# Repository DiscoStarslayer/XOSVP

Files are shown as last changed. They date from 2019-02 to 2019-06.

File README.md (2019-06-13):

# Xbox Open Source Video Project
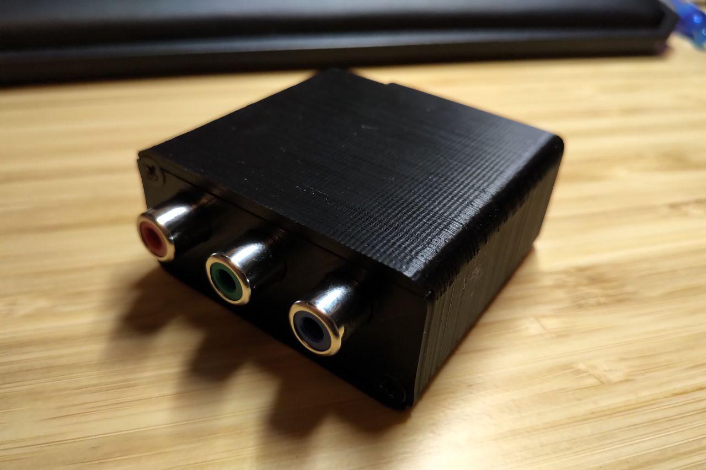
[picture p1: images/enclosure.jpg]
Finished XOSVP Image

XOSVP is an open-source alternative to the Microsoft HD AV Pack. The XOSVP strives to produce the absolute best analog video quality out of your original Xbox.

## Features
- Highest possible quality analog Y/Pb/Pr component video out
    - Impedance matched board traces and cabling from original Xbox
    - High quality video filter + amplifier, [THS7316](https://www.ti.com/lit/ds/symlink/ths7316.pdf)
        - Low pass filter removes high-frequency noise and aberrations from the source signal without harming video frequencies
        - Reconstructs + Amplifies original signal to ensure matching with the Y/Pb/Pr Standards
        - Reduces DAC Imaging effects on the video receiver
- Optical Audio/SPDIF
    - Best possible audio quality from the original Xbox
    - Support Stereo -> 5.1 Surround Sound
    - Cheap, high-quality optical DAC's easy to source on Amazon/Ebay for those without stereo systems

## More Details
[Check out my in-depth blog post on the XOSVP detailing its construction, evolution, and comparison images.](https://blog.dtho.mp/2018/12/15/xosvp-intro/)

## Designs
- [**Schematics**](/xosvp.pdf)
- [**PCB**](/pcb.png)
- [**BOM**](/bom.csv)
- [**Enclosure**](/enclosure.obj)

All designs are produced with KiCAD 5. This includes all schematic sources, designed footprints, and PCB layout.

## Enclosure
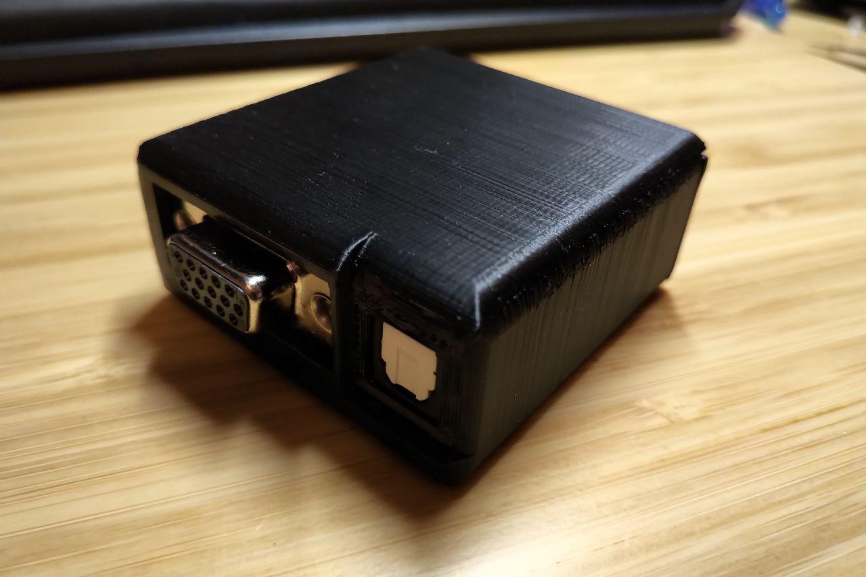
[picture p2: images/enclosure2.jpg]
XOSVP Enclosure

Also within this repo is a 3D printable enclosure for the XOSVP. It is designed for friction fit so please ensure your 3D printer is calibrated properly before printing. All files were exported with Millimeter scale.

The enclosure was designed with Tinkercad, and you can view this design [HERE](https://www.tinkercad.com/things/6Rlx4JstT6S-xosvp-enclosure-v3).

## License
I want high-quality analog video from the original Xbox to be available to everyone, which is why I open sourced this project. Everything within this repo is covered by [CERN Open Hardware License v1.2](/LICENSE).

## Contributing
If you have any suggested changes/improvements, please feel free to create an issue or a PR. They will be happily accepted!

# Build Instructions

## Kit
The Following image contains all the parts in the BOM/XOSVP DIY Kit:
Kit Contents

## PCB Installation

The parts are placed on the board in the following configuration
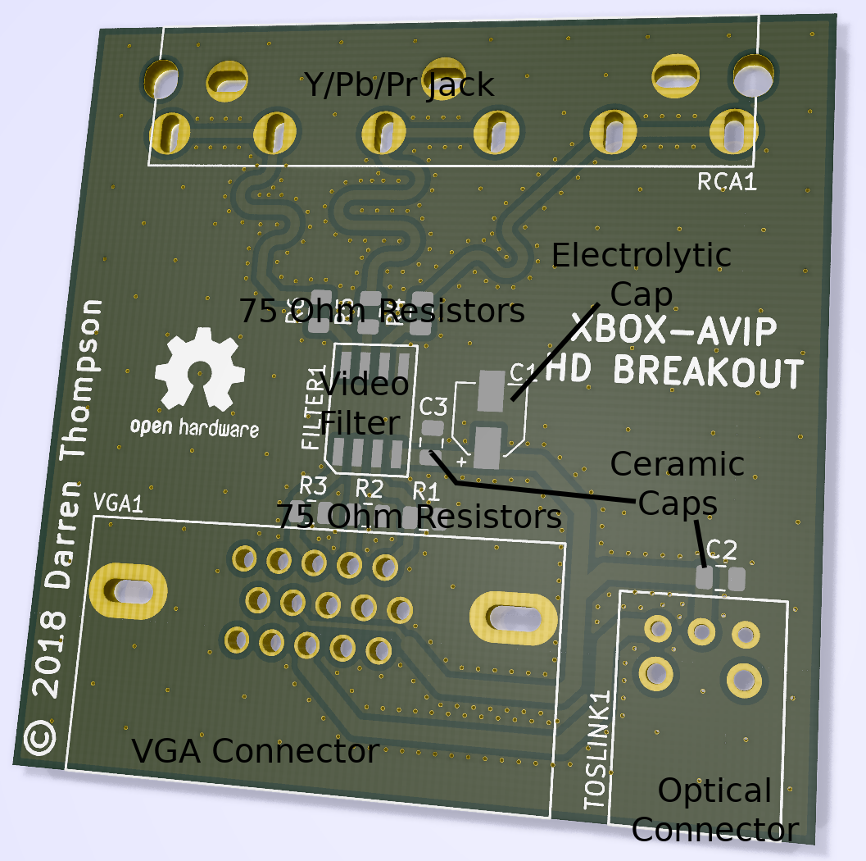
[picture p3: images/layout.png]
PCB Layout


The 3D Printed enclosure is designed for a friction fit, so it is very important that the Y/Pb/Pr jack and VGA connector are completely flush to the PCB like in the following image:
Flush Y/Pb/Pr connector

## AVIP to XOSVP
XOSVP Adapter
To make the cable that connects the Xbox to the AVIP, you will need to splice the included AVIP connector with the included VGA cable.

Creating this cable is a rather involved process, and you want to get it right, so I created the following video tutorial to document the process I follow when making them.

[**YouTube Video Tutorial**](https://www.youtube.com/watch?v=ltjp-2m_H6U)

The following pinouts are provided for extra detail and are intended to be used alongside the video tutorial.

This splice must follow the following pinout guide

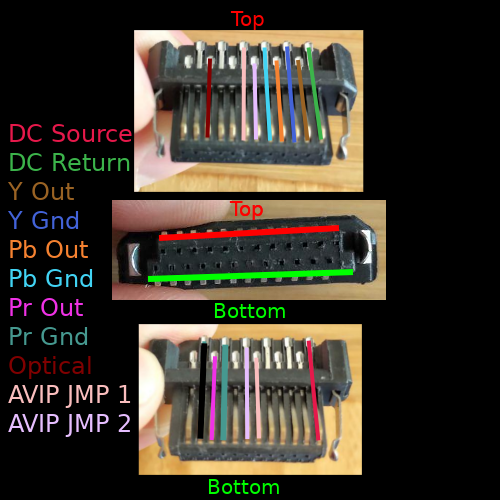
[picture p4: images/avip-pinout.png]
AVIP Pinout


Each of the colored AVIP pins must be connected so that they match the following pinout of the VGA cable. The only exception is the `AVIP JMP 1` and `AVIP JMP 2` pins. These need to be jumped together on the top + bottom of the AVIP connector.

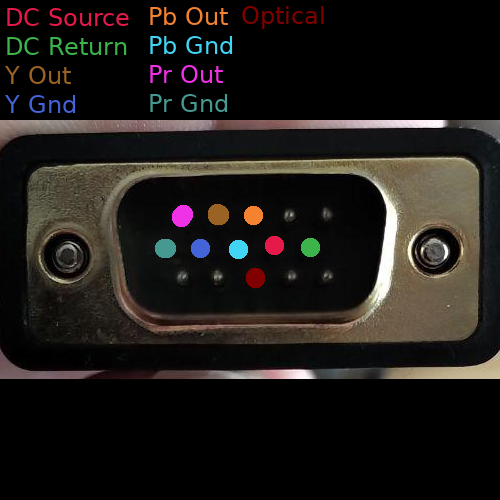
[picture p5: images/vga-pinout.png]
VGA Pinout


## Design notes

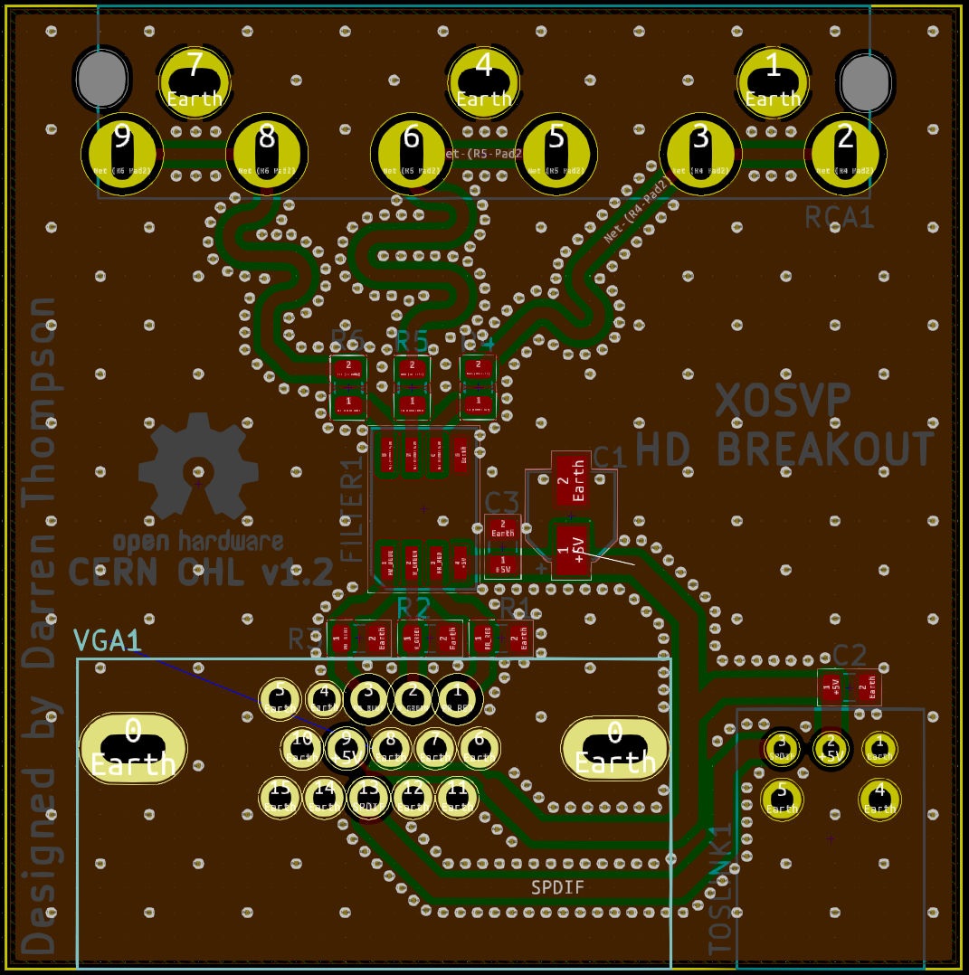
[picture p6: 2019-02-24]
pcb.png

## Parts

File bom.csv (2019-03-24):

Designator | MPN | Qty | Link
R1,R2,R3,R4,R5,R6 | CR0805-FX-75R0ELF | 6 | https://www.digikey.ca/product-detail/en/bourns-inc/CR0805-FX-75R0ELF/CR0805-FX-75R0ELFCT-ND/3740930
C1 | UCL1C100MCL1GS | 1 | https://www.digikey.ca/product-detail/en/nichicon/UCL1C100MCL1GS/493-3913-1-ND/2300340
C2,C3 | CL21B104KCFNNNE | 2 | https://www.digikey.ca/product-detail/en/samsung-electro-mechanics/CL21B104KCFNNNE/1276-6840-1-ND/5961699
FILTER1 | THS7316DR | 1 | https://www.digikey.ca/product-detail/en/texas-instruments/THS7316DR/296-26684-1-ND/2255104
VGA1 | AHDF15A-KG-TAXB | 1 | https://www.digikey.ca/product-detail/en/assmann-wsw-components/AHDF15A-KG-TAXB/AE11024-ND/1241905
RCA1 | PJRAN3X1U03X | 1 | https://www.digikey.ca/product-detail/en/switchcraft-inc/PJRAN3X1U03X/SC1854-ND/1288816
TOSLINK1 | PLT133/T10W | 1 | https://www.digikey.ca/product-detail/en/everlight-electronics-co-ltd/PLT133-T10W/1080-1430-ND/2693977
Enclosure Screw | 1455MS100BK | 2 | https://www.digikey.ca/product-detail/en/hammond-manufacturing/1455MS100BK/HM1426-ND/3869037
VGA Cable | Monoprice #5361 | 1 | https://www.monoprice.com/product?p_id=85
AVIP Connector | unk | 1 | null

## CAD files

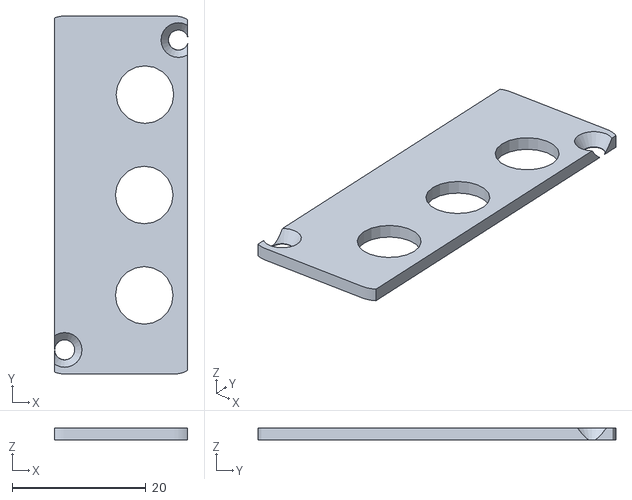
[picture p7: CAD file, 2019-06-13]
enclosure.stl
19.9 x 53.5 x 1.80

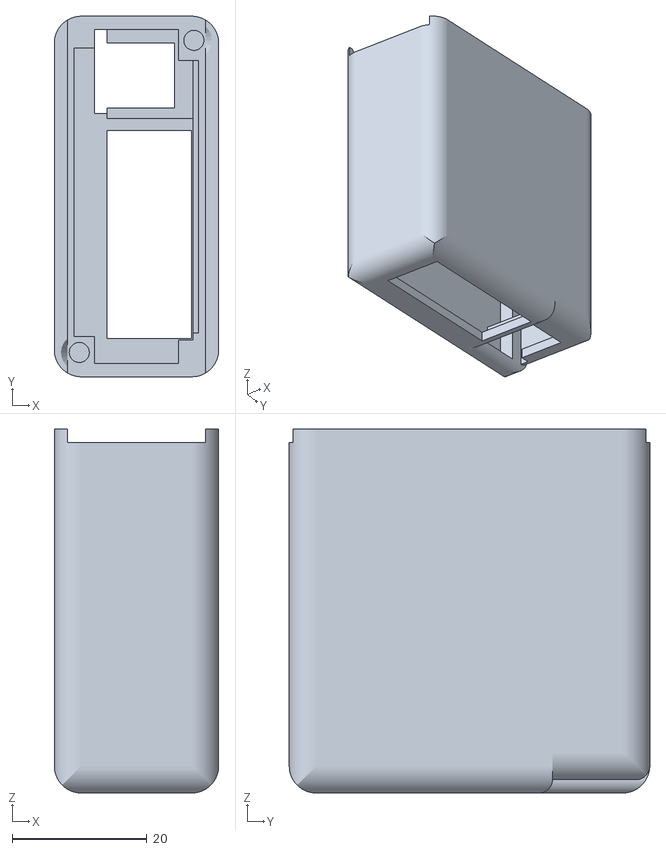
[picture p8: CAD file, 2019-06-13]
enclosure_faceplate.stl
24.4 x 53.5 x 54.0

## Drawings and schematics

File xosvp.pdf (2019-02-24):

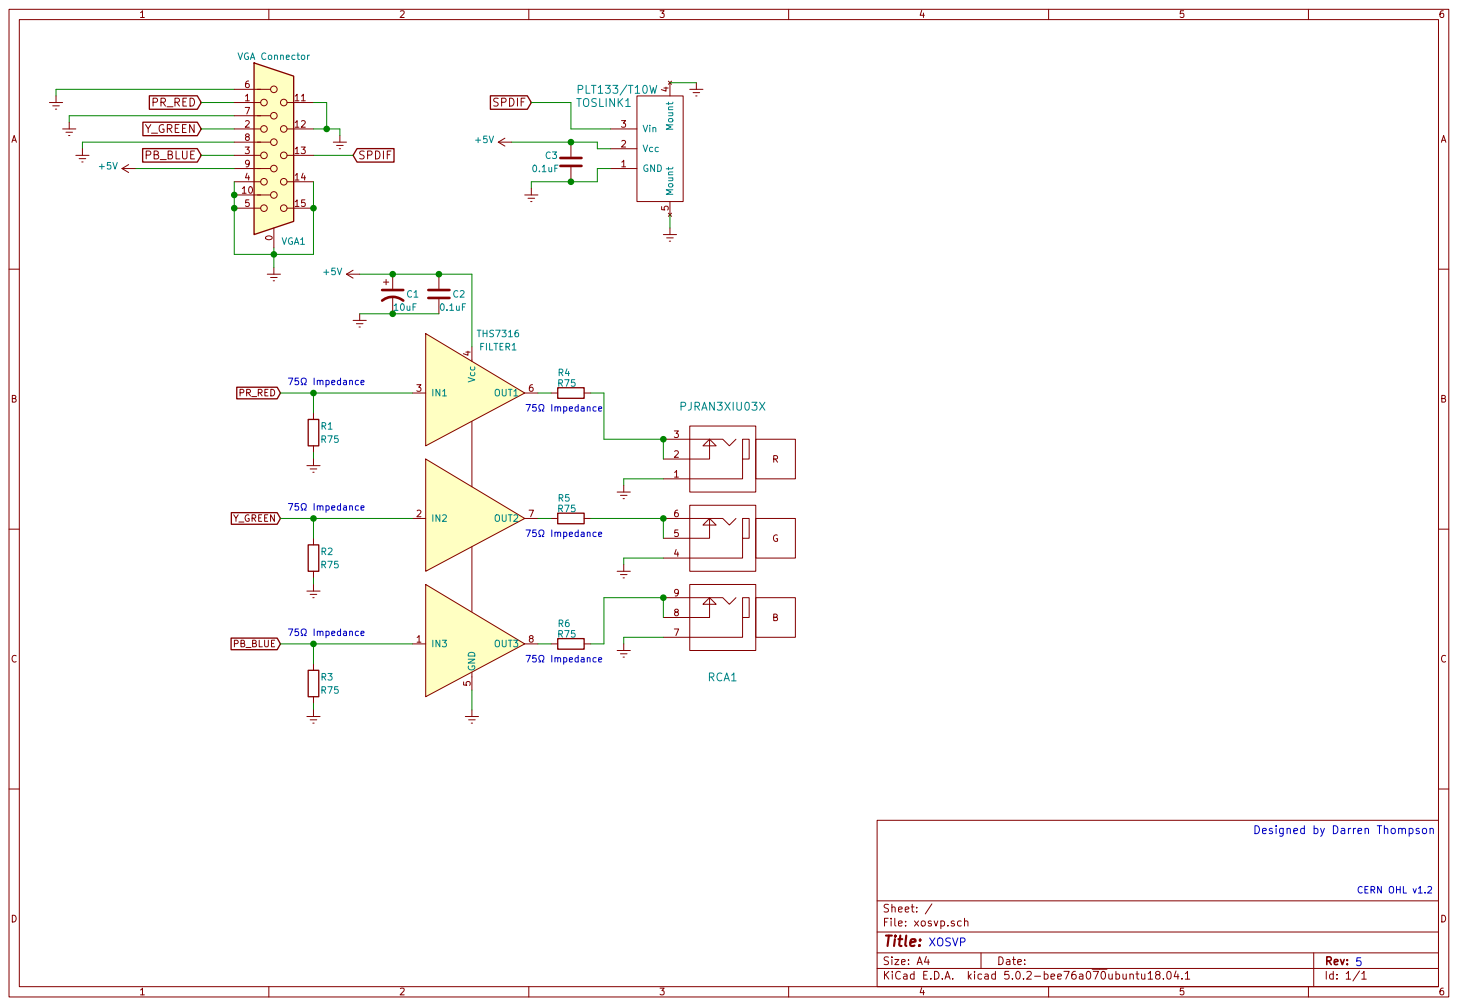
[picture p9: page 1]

5 Designed by Darren Thompson

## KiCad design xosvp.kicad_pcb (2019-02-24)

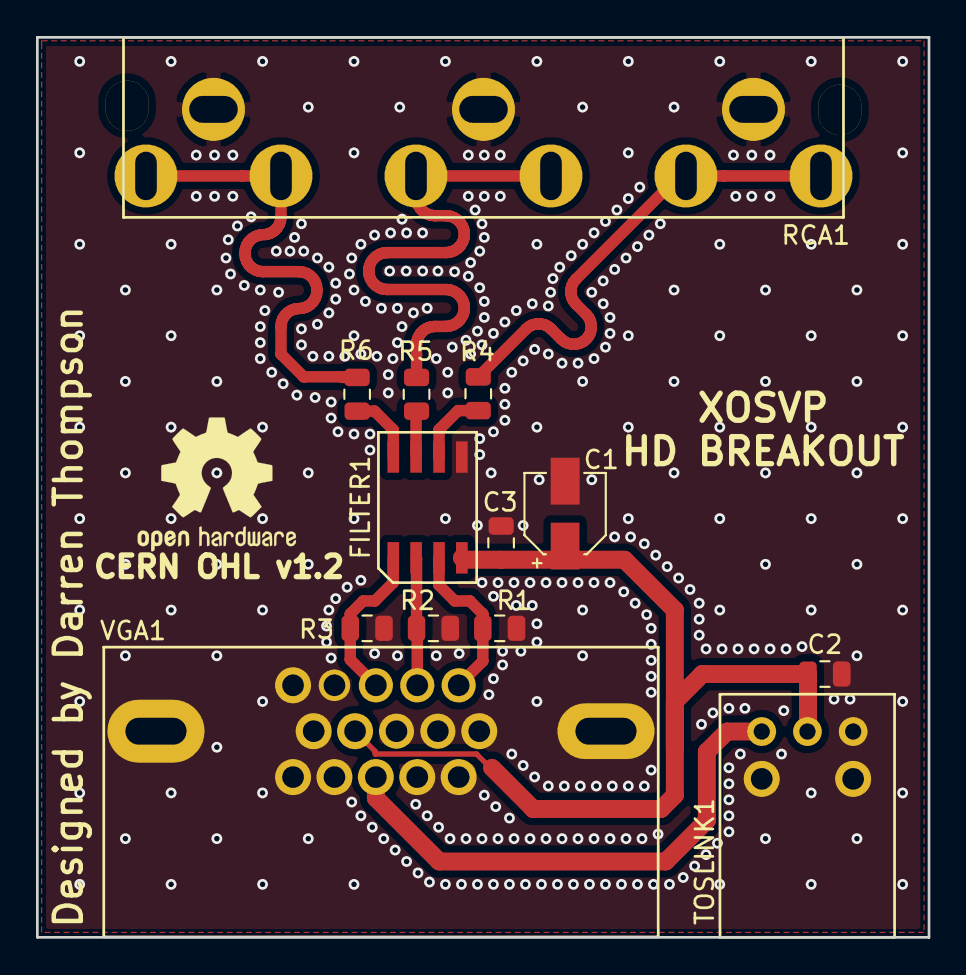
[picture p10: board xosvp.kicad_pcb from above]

Board: 2 copper layers, 49.5 x 50.0 mm, 13 parts (0 on the bottom side), 12 nets.

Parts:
C1: 10uF; CP_Elec_4x5.8
C2, C3: 0.1uF; C_0805_2012Metric
FILTER1: THS7316
R1, R2, R3, R4, R5, R6: R75; R_0805_2012Metric
RCA1: PJRAN3XIU03X; PJRAN3X1U
TOSLINK1: PLT133/T10W; PLT133
VGA1: VGA Connector; AHDF15A

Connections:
+5V: C1.1, C2.1, C3.1, FILTER1.4, TOSLINK1.2, VGA1.9
Earth: C1.2, C2.2, C3.2, FILTER1.5, R1.2, R2.2, R3.2, RCA1.1, RCA1.4, RCA1.7, TOSLINK1.1, TOSLINK1.4, TOSLINK1.5, VGA1.0, VGA1.4, VGA1.5, VGA1.6, VGA1.7, VGA1.8, VGA1.10, VGA1.11, VGA1.12, VGA1.14, VGA1.15
unnamed: FILTER1.6, R4.1
unnamed: FILTER1.7, R5.1
unnamed: FILTER1.8, R6.1
unnamed: R4.2, RCA1.2, RCA1.3
unnamed: R5.2, RCA1.5, RCA1.6
unnamed: R6.2, RCA1.8, RCA1.9
PB_BLUE: FILTER1.1, R3.1, VGA1.3
PR_RED: FILTER1.3, R1.1, VGA1.1
SPDIF: TOSLINK1.3, VGA1.13
Y_GREEN: FILTER1.2, R2.1, VGA1.2

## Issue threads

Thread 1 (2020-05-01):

Screen turned brighter all of a sudden

BanjoBanana, 2020-05-01:
I am using my XOSVP quiet a while now and i am enjoying it very much so far. After a few weeks of usage my screen turned brighter all of a sudden without any reason.

At the beginning i was able to get rid of the problem by bending the video cable a bit or by touching, which doesn‘t make any sense for me. But that worked only for a few seconds. The screen did not get any darker ever since.

I double checked every connection from AV-connector to the board. Everything seems fine. There are no solder bridges or anything. I am using an OSSC and a mClassic to get a crisper image. I haven‘t got any issues whatsoever.

What could cause this problem so that at least i know where to search? Have you ever encountered an issue like this? I would appreciate your help very much and keep up the good work!

Best regards

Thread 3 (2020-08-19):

combine analog and digital audio in one connector to enable both audio options "natively"

moosdev, 2020-08-19:
By using a regular 3.5mm TRS phone socket and a LED instead of the exclusively optical TOSLINK connector it's possible to provide optical and analog audio (with a Mini-Toslink or 3.5mm TRS cable, respectively) in one connector (and consequently gets rid of the DAC requirement if analog audio is needed).

I've come across that convenient fact when I first dug through the [MiSTer (github-)project](https://github.com/MiSTer-devel/Main_MiSTer/wiki) and its wiki.
The [IO addon board](https://github.com/MiSTer-devel/Main_MiSTer/wiki/IO-Board-Assembly-(DIY)) for it has an 3.5mm TRS phone connector (BOM: J2, BOM+schematics for further review is accessible on the linked github) which does exactly that by using a LED (BOM: LED4) behind the connector on the PCB.
[And apparently this is something which is/was used in other commercial products.](https://en.wikipedia.org/wiki/TOSLINK#Mini-TOSLINK)
(I have an assembled IO-Board on hand and can take a close-up shot of the connector and LED behind it, if needed for clarification.)

I believe the only thing to keep in mind is that the LED has to have the correct wavelength and brightness. From what I could gather from the TOSLINK specification the wavelength should be around 650-660nm. As for the brightness rating I couldn't find a specific value, but it should obviously be bright and stable enough so that it can drive the optical signal over different cable runs, at least up to spec. There's an official [support thread](http://www.atari-forum.com/viewtopic.php?f=117&t=32210) for the MiSTer IO-Board at atari-forum.com, where some values get thrown around (apparently 32-326mcd@650nm should be safe/optimal according to [one post](https://www.atari-forum.com/viewtopic.php?p=362945&sid=be3ba6345b0d4662a094e987c84c71a5#p362945)).

I just wanted to call attention to this, maybe it is a reasonable suggestion that could be integrated in an updated revision of the board (and probably the enclosure too). If you will make more, that is!

In any case, thank you for your work and for sharing it too!

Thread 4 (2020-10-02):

Adapting the kit for the PS2?

a-hurst, 2020-10-02:
Hi there,

First of all, thanks so much for the time and effort you've invested into making an affordable, high-quality, and open-source component cable option for the OG Xbox! I've been using the same cheap eBay cable for years and am looking forward to an upgrade.

As you might be aware, finding a reasonably-priced set of component cables for the PS2 has also been getting pretty challenging. Some people have taken to the old Xbox method of splicing the PS2 A/V connector with a set of X360 component cables, but I'm curious as to whether your general approach with the XOSVP (A/V connector to VGA cable + proper setup with video amp/filters on a connected board) could be easily adapted to the PS2 as well. Looking at the A/V pinout vs the Xbox, the main differences are:

* No optical audio (consoles have a dedicated TOSLINK out port already)
* One single ground for Y/Pb/Pr instead of separate ones
* No "DC Return" pin (not actually sure what this is)

The pinout I found is here:

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

The first difference would likely make things easier, but would the other two prevent any part of the XOSVP setup from working correctly? If there aren't any obvious problems, I might order an extra kit and a PS2 A/V connector and try modifying it to see if it works. Thanks in advance!

tbejos, 2021-07-18:
- For optical audio I would probably connect this to ground just to be safe but would likely be okay if left unconnected
- The separate grounds for Y/Pb/Pr are all connected to the same ground on the PCB and not kept separate so you should be good to just connect the Video ground to one of those and leave the others disconnected.
- Based on the schematic it appears that DC Return is just connected to ground on the PCB, as such it should be fine to not include it in an adapted PS2 version.

Based on all of this it definitely seems possible. I ordered some components and PCBs and will likely attempt this sometime in the next month or two and can update after I do so.

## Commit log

2019-02-24 XOSVP is ALIVE!
    [xosvp.kicad_pcb, xosvp.sch]
2019-02-24 Add BOM
    [bom.csv]
2019-02-24 Add enclosure source files
    [enclosure.obj]
2019-03-24 Add build instructions to Readme
    [bom.csv]
2019-06-13 Add new enclosure design. Fix minor issues with build instructions
    [enclosure.obj, enclosure.stl, enclosure_faceplate.stl]

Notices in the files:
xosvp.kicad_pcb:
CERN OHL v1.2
